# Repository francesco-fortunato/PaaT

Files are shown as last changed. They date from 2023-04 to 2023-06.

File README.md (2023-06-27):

# PaaT - Pet as a Thing!
Internet of Things project for the Internet of Things Algorithm and Services 2022/23 course held by Andrea Vitaletti and Ioannis Chatzigiannakis.

## People

[Francesco Fortunato](https://www.linkedin.com/in/francesco-fortunato-a68094181/) 

[Valerio Francione](https://www.linkedin.com/in/valerio-f-9000a557/)

[Andrea Sepielli](https://www.linkedin.com/in/andreasepielli/)

## Description

This project aims to develop a pet tracking system that utilizes an ESP32 Heltec LoRa v2 and GPS module to track pets' movements. The system allows pet owners to monitor their pets' location, view their pets' movement history, and receive alerts when their pets leave a designated area.

## Before Starting
Clone the repository
```
https://github.com/francesco-fortunato/PaaT.git
```

### Init and update the submodules
Execute `cd PaaT`.

#### Init submodule
```
git submodule init
```
#### Update the submodule
```
git submodule update
```

[Link to the user interface](https://main.d24229we7y3qnn.amplifyapp.com/)

## Final Delivery

### Docs

- [Concept](docs/Final_Concept.md)
- [Design](docs/Final_Design.md)
- [Evaluation](docs/Final_Evaluation.md)
- [Presentation](https://docs.google.com/presentation/d/1p3-u78l3DJtRwXcR-sK6B_98UEg3uL_TondBaY1GaM8/edit?usp=sharing)

### Video

- [Blog Post](https://www.hackster.io/paat/a-low-power-geofencing-application-with-riot-os-and-iot-lab-8825f0)
- [Demo](https://youtu.be/FwU-OgtWOeE)
- [Presentation](https://youtu.be/GNf6_sShy98)

## First Delivery

### Docs
- [Concept](docs/Concept.md)
- [Design](docs/Design.md)
- [Evaluation](docs/Evaluation.md)

### Video
- [Link to Youtube Video](https://youtu.be/oAYv7sOTY6s)

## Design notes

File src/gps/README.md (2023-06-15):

# Paat using Wi-Fi connection and MQTT

#### UART PIN CONFIGURATION ON ESP32 HELTEC LORA32 WIFI (V2)

In order to let the E108-GN02D GPS module work with ESP32 Heltec Lora V2 in Riot OS, we should edit the default pins of UART configuration:

Open the file `RIOT/boards/esp32-heltec-lora32-v2/include/periph_conf.h`

Edit the lines:

```
#ifndef UART1_TXD
#define UART1_TXD   GPIO10  /**< direct I/O pin for UART_DEV(1) TxD */
#endif
#ifndef UART1_RXD
#define UART1_RXD   GPIO9   /**< direct I/O pin for UART_DEV(1) RxD */
```

To make them like this:

```
#ifndef UART1_TXD
#define UART1_TXD   GPIO17  /**< direct I/O pin for UART_DEV(1) TxD */
#endif
#ifndef UART1_RXD
#define UART1_RXD   GPIO16   /**< direct I/O pin for UART_DEV(1) RxD */
```

Then connect the TXD of the GPS to PIN 16 and the RXD of the GPS to PIN 17

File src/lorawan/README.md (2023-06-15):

# PaaT based on LoRa

This folder contains the main.c file of the app using LoRa, along with the Makefile.

This code is used to make simulation on FIT IOT-LAB by using the board st-lrwan1 in the Saclay site. Compile it using `make all term`, then inside bin/b-l072z-lrwan1 you will find the lorawan.elf file. 

Let's go through the code and understand its main components:

#### Joining the LoRaWAN Network:

The application is using Over-The-Air Activation (OTAA), so it converts identifiers and keys to byte arrays.
The code sets the LoRaWAN data rate and checks if the device has already joined the network. If not, it attempts to join the network using the joinLoRaNetwork() function, a function defined since sometimes the join is not successful, which the purpose is to retry if the join fails.
If the network join is successful, the configuration is optionally saved to EEPROM.

#### Sending Geofence Request:

The code allocates memory for a geofence request message and constructs the JSON message using the "geofence" keyword.
The message is then sent using the semtech_loramac_send() function.

#### Receiving Geofence Data:

After a delay of 2 seconds, the code wakes up a receiver thread (_recv) to receive geofence data.
The received message is parsed and the geofence values are extracted and stored in the geofence array.

#### Geofence Violation Checking:

The code enters an infinite loop where it waits for a reliable position or a timeout.
In this example, latitude and longitude values are hardcoded for demonstration purposes.

The code checks if the number of satellites is greater than or equal to 4, and if so, determines if the current position is within the geofence using the isInGeofence() function. The code is simulating a scenario in which when the board is initialized, the pet is inside the geofence, while after 10 minutes it exit.

If the geofence is violated, is turned on an LED, is encrypted and sent the latitude and longitude coordinates using AES encryption, and is performed a sleep for 300 seconds.

If the geofence is not violated, it prints a message, turns off the LED, sets soundOn and lightOn flags to false, and sleeps for 300 seconds. Of course this because there is no need to know the actual position of the pet since it is inside the geofence.

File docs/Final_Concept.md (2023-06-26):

# Concept 

This document serves as the final concept report for the project. For the previous version, please refer to [this link](https://github.com/francesco-fortunato/PaaT/blob/main/docs/Concept.md).

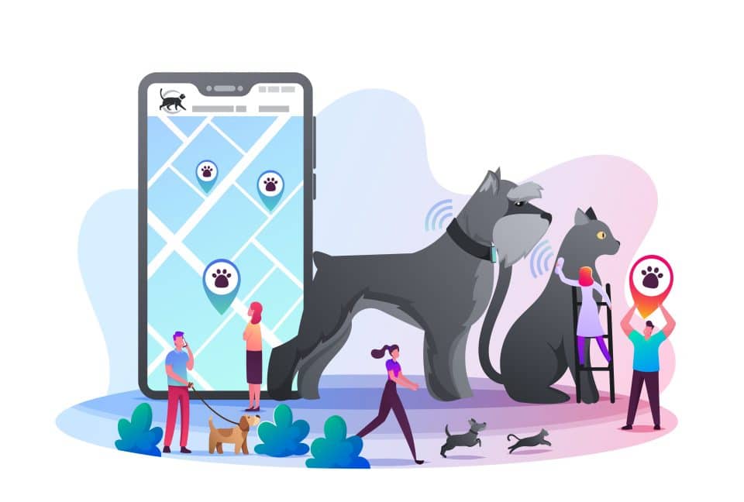
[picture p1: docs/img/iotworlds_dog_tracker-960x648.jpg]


## The Problem 

Owning a pet offers numerous health benefits, including increased exercise, outdoor activities, and social interaction. Pets provide companionship and can help alleviate feelings of loneliness and depression. However, losing a pet is an extremely distressing experience for their owners.

While the issue of lost pets is widely acknowledged, obtaining accurate statistics is challenging due to the lack of a national reporting system. In 2009, according to the American Humane Association **1 out of 3** pets become lost at some point in their lifetime (**33%**) and close to **10 million** dogs and cats are lost or stolen in the US every single year. According to the Coalition for Reuniting Pets and Families, **less than 23%** of lost pets in the United States are reunited with their owners.
We can synthesize this with:
- **over 135 millions of dogs and cats in the United State**
- **33% of ALL dogs and cats in the USA go MISSING**
- **more than 80% of missing pets are NEVER FOUND**

In 2016, [Peeva](https://peeva.co/blog/missing-pet-epidemic-facts-and-figures) conducted a survey sporadically over the course of several months in 2016 to get a more accurate gauge of the approximate percentage of owned dogs and cats in the United States that are reported lost, and of these reported lost pets (specifically dogs and cats), the percentage that are reclaimed by their owners (those that reported the pets as lost) by surveying a sample set indicative of the US pet owning population as a whole. The results and conclusions were surprising: the previous statistics reported are actually the same as their findings.
- **over 135 millions of dogs and cats in the United State**
- **33% of ALL dogs and cats in the USA go MISSING**
- **more than 80% of missing pets are NEVER FOUND**

Moreover, we conducted some studies on **HOW** pets were found. We found out that ID or Microchip, other "valid" elements, represents only the **2-10%** for helping find pets.

## A possible solution

A possible solution for the problem could be to use a GPS system. 
GPS system used for tracking pets already exists, but they presents some lacks:
- **The module cannot be disassembled**, so issues related to battery, radio or GPS malfunction cannot be fixed easily and the whole device must be replaced
- The recognized **location is not accurate** when there is **no affordable satellite signal** (and **no information** about this is given **to the end user**)
- There are **no actuators** that let the user find the pet in though scenarios, as in the night or in hidden places (bushes, walls, enclosed areas…)
- Sensors that allow user to know if his pet is steady for too long are missing (pet could have lost tracker or have health issues)
- An **history** of last day **positions** is missing
- GSM subscription is **costly** due to licencing (**€60/year**)

An **IoT GPS system**, insted, could provide:
- A **solution** for all the requirements above.
- **Improved Recovery Rates**: in case a pet gets lost, the tracking capability and low power consumption of significantly increases the chances of finding and recovering them.
- **Continuous Monitoring**: owners can access to information about their pet's movements and behavior patterns over time. 
- **Remote Access**: owners can remotely access their pet's location information through mobile applications or web interfaces.
- **Integration with Other Devices**: For example, it can be sync with smart home systems, allowing automated alerts to be sent to multiple devices or triggering actions like opening a pet door when the pet approaches. 
- **Data Analytics**: generate a wealth of data regarding a pet's activities, location history, and health metrics. This data can be analyzed to gain insights into the pet's behavior, exercise patterns, sleep quality, and more.

So, we based user requirements on the precedent ones (that were not satisfied) and on some interviews we made during the lessons.

## User Requirements

- It has to work for
  - **At least 24 hours**: in case we lose our pet it is important that the device remains active for at least one day, that could be a sufficient amount of time to track and retrieve it;
  - **At least one month**: in case we do not lose contact with our pet, it is sufficient that the device remains active for at least one month. This period of time can be used by the user if he will stay out for days, and it’s also a good trade-off between time required to retrieve the pet and efficiency consumption from a user point of view.

- Sampling time and promptly:
  - **5 min**: when we lose the contact with the pet, 5 minutes could be a sufficient amount of time to update the position, because in 5 minutes the pet could not do so much road, and the user can rescue it;

- Accuracy:
  - **10-15m**, that is a sufficient range in order to be able for the user to find his pet.
  - **False positive** and **false negative** has to be detectable.

- Security: 
  - data exchanged by the application must be **encrypted** in order to hide sensitive information (like the position of the pet) to malicious attackers, providing **confidentiality** to the end user.

- Events: 
  - {"latitude": float, "longitude": float, “sat_num”: int}: since data transfer size are in the order of 2^7 bytes (+ headers) and since we need that the system has to be energy efficient that supports a communication in the order of ≈10 km, free, **LoRa** is strongly suitable for our system.

## Offered Services

The pet tracking system will have the following features:
- **Location Tracking**: The system utilizes GPS technology to track pets' location;
- **Geofencing**: Pet owners can set up a designated area for their pets, and the system will send an alert when the pet leaves the designated area;
- **Movement history**: The system keeps track of pets' movements and displays the data in a graphical format for pet owners to review;
- **Notifications**: Pet owners receive en email when their pets leave the designated area that incities the owner to access the site.

## Service Details
To use the pet tracking system, pet owners must first attach the GPS system to their pet's collar or harness. The system is powered by a battery, and the battery life will depend on the position of the pet, if it is in the geofence the device does not track the animal, on the other hand if the pet is outside the geofence, the device will update the position every 5 minutes.

Pet owners can access the system's features through a web interface. The web interface allows pet owners to view their pets' location, movement history, and set up geofencing. 

When pet owners set up geofencing, they can define a specific area where their pet is allowed to roam. If the pet leaves the designated area, the system sends an alert to the pet owner's email address. Pet owners can then use the web interface to track their pet's location and retrieve their pet.

## Conclusion
Pet tracking is a crucial aspect of pet ownership, and this IoT Pet Tracking System can provide a reliable and efficient solution for pet owners. With location tracking, geofencing, movement history, and notifications, pet owners can keep an eye on their pets' location and ensure their pets' safety, improve recovery rates, and so on.

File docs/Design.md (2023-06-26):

# Design

## Conceptual Architecture
The pet tracking system architecture consists of two main components: an ESP32 v2 Heltec LoRa, with the GPS module. The ESP32 is responsible for collecting location data from the GPS module, processing the data, and sending it to the receivers. Then, the receivers will be responsible for sending the data to AWS cloud service for storage and analysis.

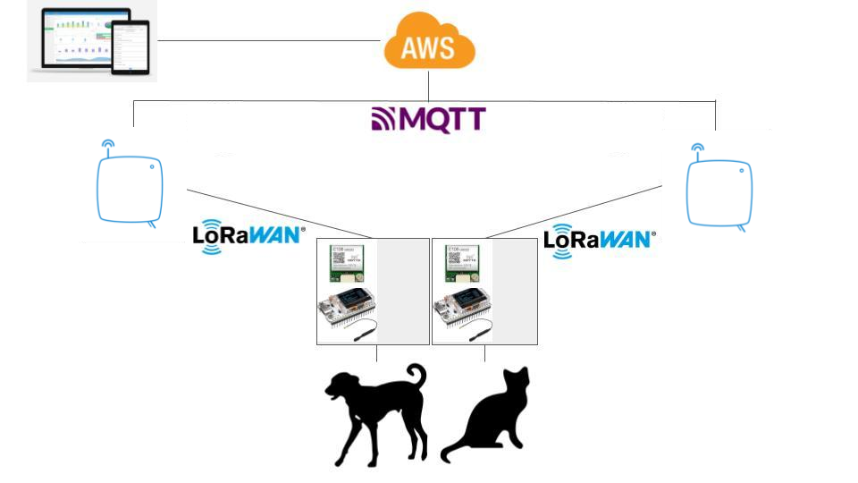
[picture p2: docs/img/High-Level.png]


The cloud service is responsible for storing the pet's location data, analyzing the data, and sending alerts to the pet owner when their pet leaves the designated area. The pet owner can access the cloud service through a web interface.

## Hardware Components
ESP32 v2 Heltec LoRa board
The ESP32 v2 Heltec LoRa board is the primary hardware component of the pet tracking system. There are two ESP32 in our system: one is responsible for collecting location data from the GPS module, processing the data, and sending it to the receiver; the other is the receiver itself, that is responsible responsible for sending the data to AWS cloud service. The two modules has a built-in LoRa transceiver that allows them to communicate with each other over long distances.

GPS Module
The GPS module is responsible for getting location data. The module communicates with the ESP32 v2 Heltec LoRa module over a serial connection.

Buzzer
The buzzer is used to emit a loud sound in the case in which the pet owner wants to find his pet and he cannot see it.

LED
The LED is also used to flash in the case in which the pet owner cannot find his pet during the night.

Battery
The battery is responsible for providing energy to the ESP32 board.

## Software Components
Core Algorithms
The pet tracking system uses several core algorithms to function correctly. The algorithms are responsible for collecting location data, processing the data, and sending alerts to the pet owner when their pet leaves the designated area.

Network Protocols
The pet tracking system uses the LoRaWAN protocol to communicate between the ESP32 v2 Heltec LoRa and GPS module and the cloud service. LoRaWAN is a low-power, wide-area network protocol that allows for long-range communication between devices.

## Network Architecture

                +-------------+
                |      DB     |
                +-------------+
                         |
                         |
                         |
             +----------------+
             | Cloud Service  |
             +----------------+
                         |
                         |
                         |
           +-----------------+
           | LoRaWAN Receiver|
           +-----------------+
                         |
                         |
                         |
          +-------------------+
          | ESP32 v2 Heltec  |
          | LoRa and GPS     |
          | Module, Battery, |
          | Buzzer, LED      |
          +-------------------+

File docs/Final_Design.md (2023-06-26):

# Design

This document serves as the final design report for the project. For the previous version, please refer to [this link](https://github.com/francesco-fortunato/PaaT/blob/main/docs/Design.md).

## Conceptual Architecture



The pet tracking system architecture consists of: 
- an Heltec ESP32 LoRa WiFi board with a GPS module, battery, buzzer and LED;
- The Things Network, that acts as a gateway for communication between the ESP32 and the cloud service. It ensures seamless data transfer and enables long-range communication.
- The cloud service, a component that stores the pet's location data, performs data analysis, and generates alerts when the pet leaves the designated area. Pet owners can access the cloud service through a user-friendly web interface.

## Hardware Components

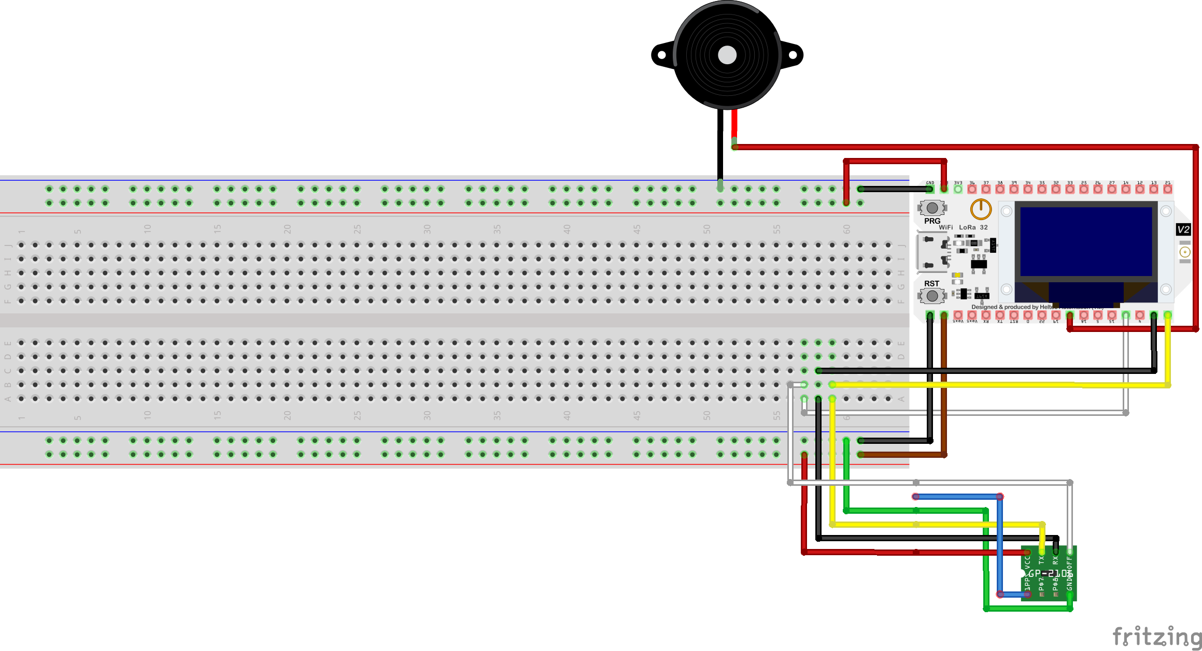
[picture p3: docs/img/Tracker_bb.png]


To enable effective pet tracking, monitoring and alerting, the pet tracking system incorporates the following hardware components:

1. ESP32 v2 Heltec LoRa board: The primary hardware component responsible for collecting location data from the GPS module, processing it, and transmitting it to the Things Network. 

2. GPS Module: The GPS module interfaces with the ESP32 v2 Heltec LoRa board through a serial connection (UART), providing accurate location data.

3. Buzzer: The system incorporates a buzzer that emits a loud sound to assist pet owners in locating their pets.

4. LED: An LED is integrated into the system to provide visibility during nighttime, aiding pet owners in locating their pets.

5. Battery: The battery serves as the primary power source for the ESP32 board, ensuring uninterrupted operation.

## Software Components

### Core Algorithm:

The algorithm works as follow:

#### Joining the LoRaWAN Network:

The application is using Over-The-Air Activation (OTAA).
The code sets the LoRaWAN data rate and checks if the device has already joined the network. If not, it attempts to join the network using the joinLoRaNetwork() function, a function defined since sometimes the join is not successful, which the purpose is to retry if the join fails.

#### Sending Geofence Request:

The code allocates memory for a geofence request message and constructs the JSON message using the "geofence" keyword.
The message is then sent using the semtech_loramac_send() function.

#### Receiving Geofence Data:

The code wakes up a receiver thread (_recv) to receive geofence data.
The received message is parsed and the geofence values are extracted and stored in the geofence array.

#### Geofence Violation Checking:

The code enters an infinite loop where it waits for a reliable position or a timeout.

The code checks if the number of satellites is greater than or equal to 4, and if so, determines if the current position is within the geofence using the isInGeofence() function. 

If the geofence is violated, is turned on an LED, is encrypted and sent the latitude and longitude coordinates using AES encryption, and is performed a sleep for 300 seconds.

If the geofence is not violated, it prints a message, turns off the LED, sets soundOn and lightOn flags to false, and sleeps for 300 seconds. Of course this because there is no need to know the actual position of the pet since it is inside the geofence.

### Network Protocols

#### LoRaWAN

LoRaWAN (Long Range Wide Area Network) is an industry-standard protocol specifically designed for low-power, wide-area networks. It enables long-range communication between devices while consuming minimal power. The utilization of LoRaWAN in the pet tracking system ensures that the location data from the ESP32 v2 Heltec LoRa board and GPS module can be transmitted efficiently to the cloud service.

LoRaWAN's unique properties make it exceptionally suitable for this project. It provides long-range coverage, allowing reliable communication between the pet tracking devices and the cloud service even over considerable distances. Moreover, LoRaWAN operates in the unlicensed spectrum, ensuring cost-effective deployment and scalability, instead of nowadays solutions. By employing LoRaWAN, the pet tracking system achieves extended battery life for the tracking devices while maintaining a robust and reliable network connection.

#### MQTT (Message Queuing Telemetry Transport)

MQTT is a lightweight messaging protocol designed for efficient communication between devices in IoT applications. It follows a publish-subscribe messaging pattern, where devices can publish data to specific topics, and other devices can subscribe to those topics to receive the published data.

In our project, MQTT is used to establish a seamless connection between the cloud service and the AWS IoT Core. The Things Network (TTN) stack, integrated with MQTT, enables data transmission from the pet tracking devices to AWS IoT Core.

The utilization of MQTT offers numerous advantages. It ensures efficient and reliable data transfer, even in constrained network environments. MQTT's lightweight nature minimizes network overhead and conserves energy consumption, aligning perfectly with the low-power requirements of the pet tracking system. Furthermore, MQTT's support for Quality of Service (QoS) levels enables the system to guarantee message delivery, ensuring the pet's location data reaches the AWS IoT Core without loss or compromise.

By combining LoRaWAN and MQTT, PaaT achieves a robust and efficient network infrastructure. LoRaWAN provides long-range connectivity, while MQTT facilitates seamless integration with AWS IoT Core, allowing pet owners to access real-time location data and receive timely alerts through the cloud service's web interface.

## Network Architecture

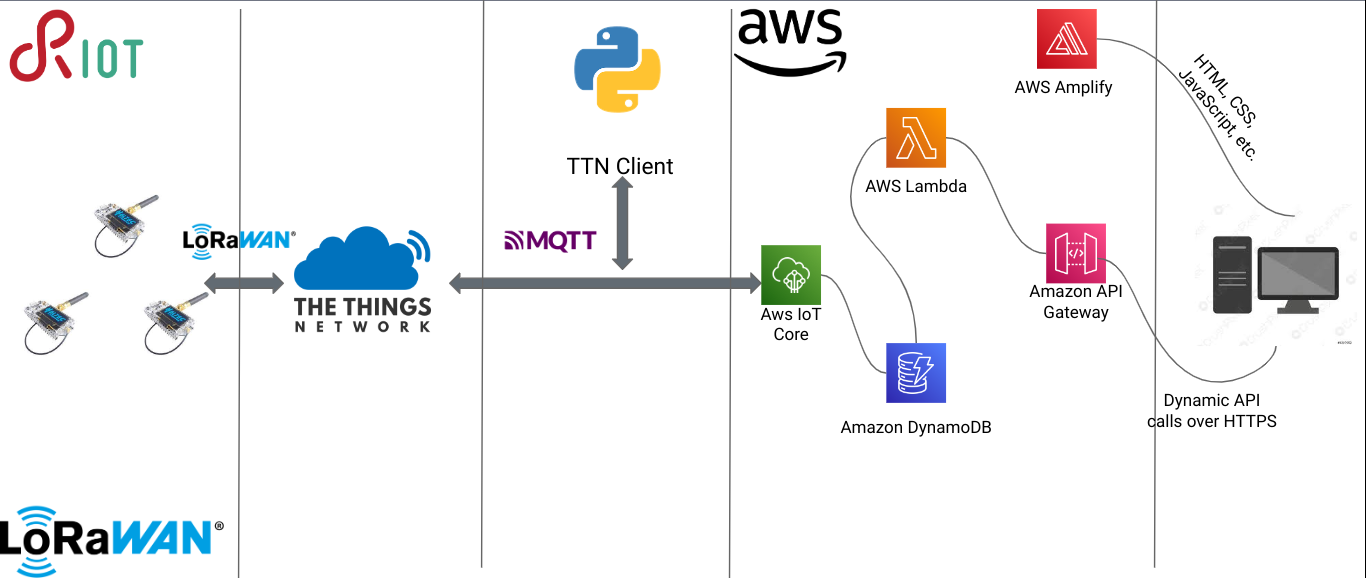
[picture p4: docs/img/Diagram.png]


The network architecture comprises the following elements:

### IoT Devices with RIOT OS
The pet tracking system utilizes IoT devices equipped with the RIOT OS (Real-Time Operating System). These devices, such as the ESP32 v2 Heltec LoRa board, incorporate the necessary hardware components, to track and monitor pets effectively. RIOT OS provides a lightweight and efficient operating system tailored for resource-constrained IoT devices, ensuring optimal performance and low power consumption.

### The Things Network (TTN)
The Things Network plays a crucial role in the pet tracking system's network architecture. TTN serves as the LoRaWAN infrastructure provider, enabling secure and reliable communication between the IoT devices and the cloud service. It facilitates the seamless transmission of location data from the IoT devices to the cloud service, ensuring efficient data flow and connectivity.

### Python client for interfacing with TTN
To facilitate the configuration of geofence boundaries, a Python TTN client is employed. This client interacts with TTN to provide the precise coordinates of the geofence to the IoT devices. By leveraging this client, the system establishes an effective means of defining and updating the designated area in which pets should remain.

### Amazon Web Services

The pet tracking system leverages several components within the AWS ecosystem to enable data storage, processing, and web interface access. The components utilized include:

- AWS IoT Core: It serves as the central hub for communication between the pet tracking devices and the cloud service. AWS IoT Core enables secure and reliable data exchange and facilitates seamless integration with other AWS services.

- DynamoDB: This NoSQL database service is employed for storing the pet's location data. DynamoDB offers scalability, high performance, and low latency access, ensuring efficient storage and retrieval of location data.

- Lambda Functions: AWS Lambda functions are utilized to perform various operations on the pet's location data, including encryption, decryption, and data processing. These serverless functions enable real-time data manipulation and facilitate seamless integration with other AWS services.

- Amplify: AWS Amplify simplifies the development process by providing a set of tools and services for building scalable and secure web applications. It enables the creation of a user-friendly web interface for pet owners to access real-time location data and receive alerts.

- API Gateway: AWS API Gateway acts as the entry point for the web interface, providing a secure and scalable API endpoint. It enables seamless communication between the web interface and the backend services, ensuring a smooth user experience.

The user interface is reachble through this [link](https://main.d24229we7y3qnn.amplifyapp.com/)

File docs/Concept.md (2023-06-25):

# Concept 

## Introduction 
Pet tracking is an essential aspect of pet ownership, and it can be challenging to keep an eye on pets at all times. This project aims to develop a pet tracking system that utilizes an ESP32 Heltec LoRa v2 and GPS module to track pets' movements. The system allows pet owners to monitor their pets' location, view their pets' movement history, and receive alerts when their pets leave a designated area.



## Features
The pet tracking system has the following features:
- location tracking: The system utilizes GPS technology to track pets' location in real-time.
- Geofencing: Pet owners can set up a designated area for their pets, and the system will send an alert when the pet leaves the designated area.
- Movement history: The system keeps track of pets' movements and displays the data in a graphical format for pet owners to review.
- Notifications: Pet owners receive en email when their pets leave the designated area that incities the owner to access the site.

## Service Details
To use the pet tracking system, pet owners must first attach the ESP32 Heltec LoRa v2 with GPS module to their pet's collar or harness. The system is powered by a battery, and the battery life will depend on the position of the pet, if it is in the geofence the device does not track the animal, on the other hand if the pet is outside the geofence, the device will update the positiono every 5 minutes.

Pet owners can access the system's features through a web interface. The web interface allows pet owners to view their pets' location, movement history, and set up geofencing. The web interface also allow to the user to active a light and a sound signal, in order to make easier find the pet in low-visibility condition.

When pet owners set up geofencing, they can define a specific area where their pet is allowed to roam. If the pet leaves the designated area, the system sends an alert to the pet owner's email address. Pet owners can then use the web interface to track their pet's location and retrieve their pet.

## Conclusion
Pet tracking is a crucial aspect of pet ownership, and this pet tracking system using ESP32 Heltec LoRa v2 and GPS module can provide a reliable and efficient solution for pet owners. With location tracking, geofencing, movement history, and notifications, pet owners can keep an eye on their pets' location and ensure their pets' safety.

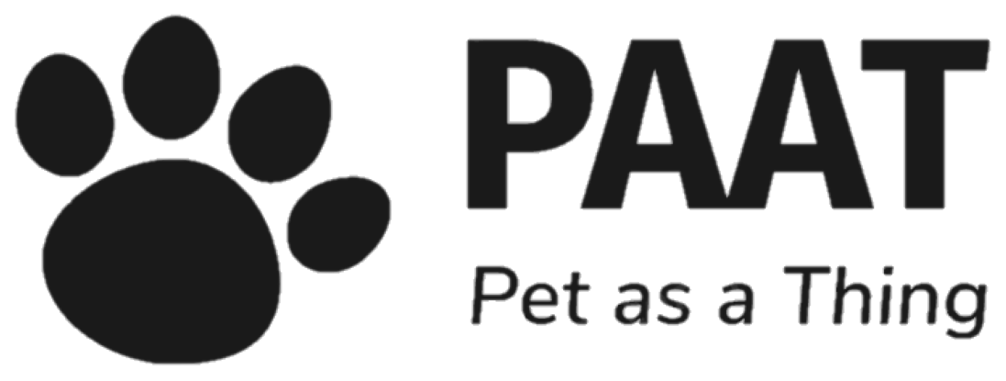
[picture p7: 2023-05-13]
cloud/user-interface/dist/paat/assets/paat.png

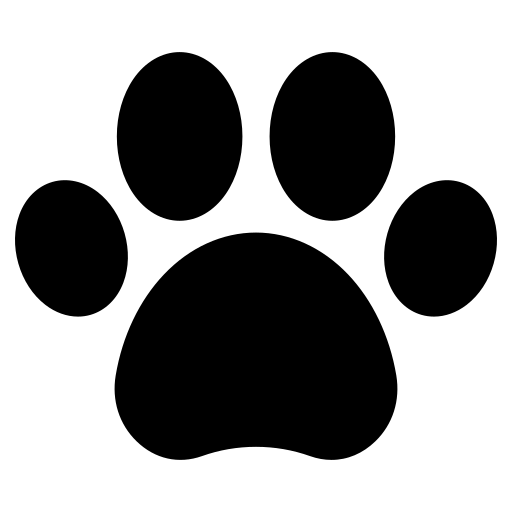
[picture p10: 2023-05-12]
cloud/user-interface/dist/paat/assets/pet.png

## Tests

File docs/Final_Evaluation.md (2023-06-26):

# Evaluation Report

This document serves as the final evaluation report for the project. For the previous version, please refer to [this link](https://github.com/francesco-fortunato/PaaT/blob/main/docs/Evaluation.md).

To evaluate the product we studied and investigated the connection via LoRa and the power consumption and management,
due to the activation of GPS only in case the animal is inside the geofence, and GPS combined with buzzer and LED in case the animal is outside the geofence instead.
The evaluation primarily focused on two key aspects: the LoRaWAN connection and power consumption and management. Detailed investigations were conducted to understand and to assess the power requirements and consumption patterns of the prototype. The following sections provide a thorough overview of the evaluation findings.

## LoRaWAN

To evaluate the LoRaWAN connection, a specialized tool offered by FIT IoT-LAB was utilized. The developed code for transmitting data was uploaded to the tool, and a series of tests were conducted. The test results demonstrated the performance of the LoRaWAN connection, with specific attention given to power consumption during data transmission.

The obtained results are graphically represented in the figure below:

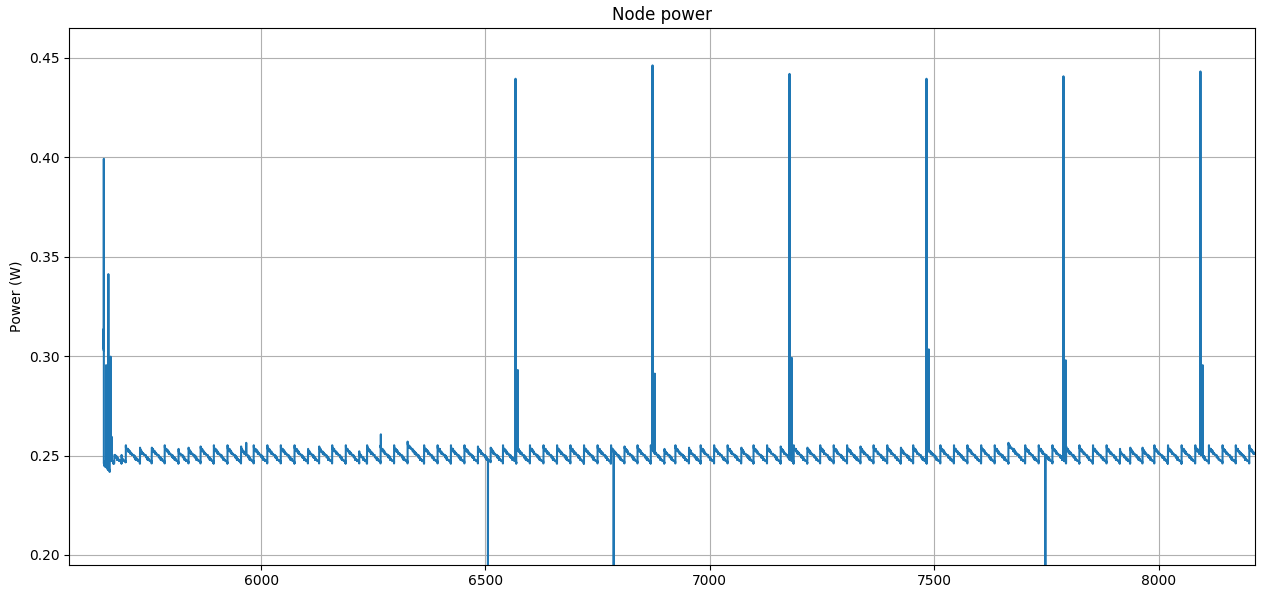
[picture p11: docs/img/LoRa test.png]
LoRa test


The graph reveals distinctive peaks in power consumption corresponding to message transmissions. Notably, the highest peak corresponds to the sending of messages, while the smallest peak aligns with the reception of response messages. To further analyze these peaks, detailed breakdowns are presented in the subsequent figures:

- Sending and response messages in detail:

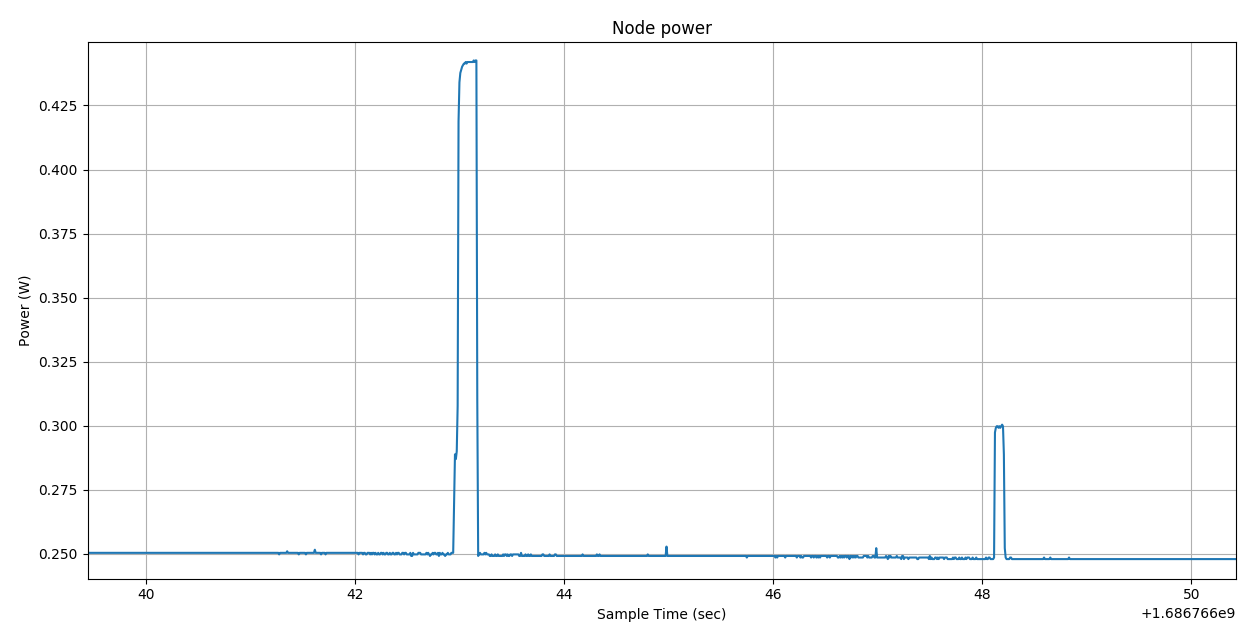
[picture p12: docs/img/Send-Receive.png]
Sending and response messages in details


- Power consumption during message transmission:
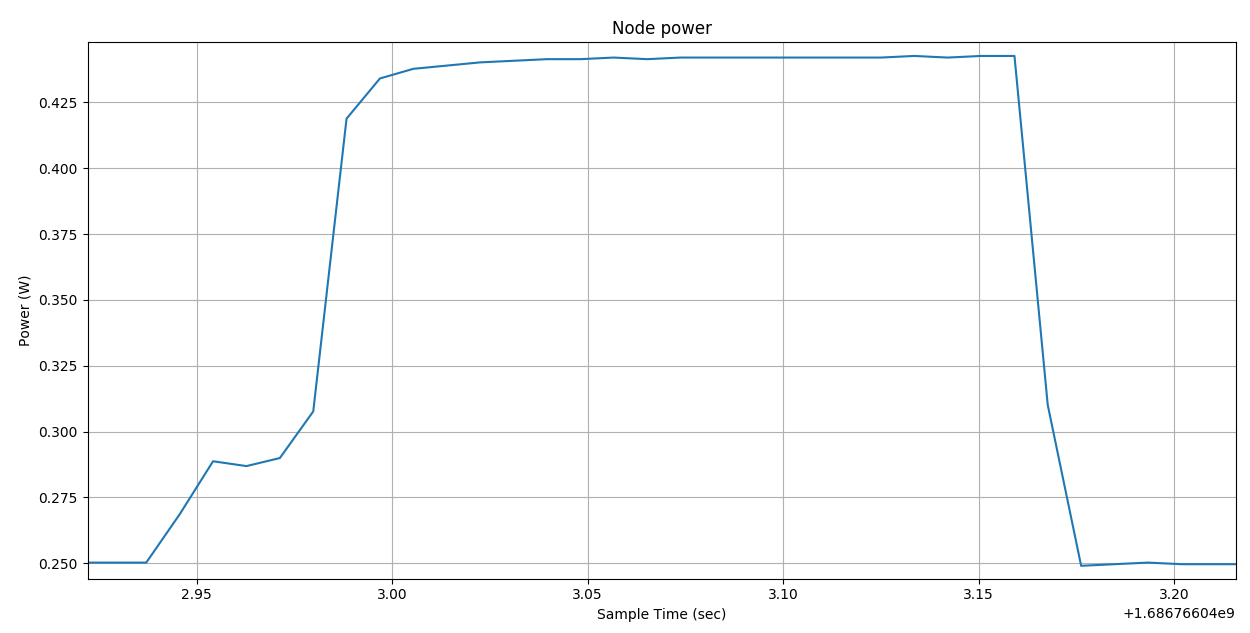
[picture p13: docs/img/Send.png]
Send message


- Power consumption during response message reception:
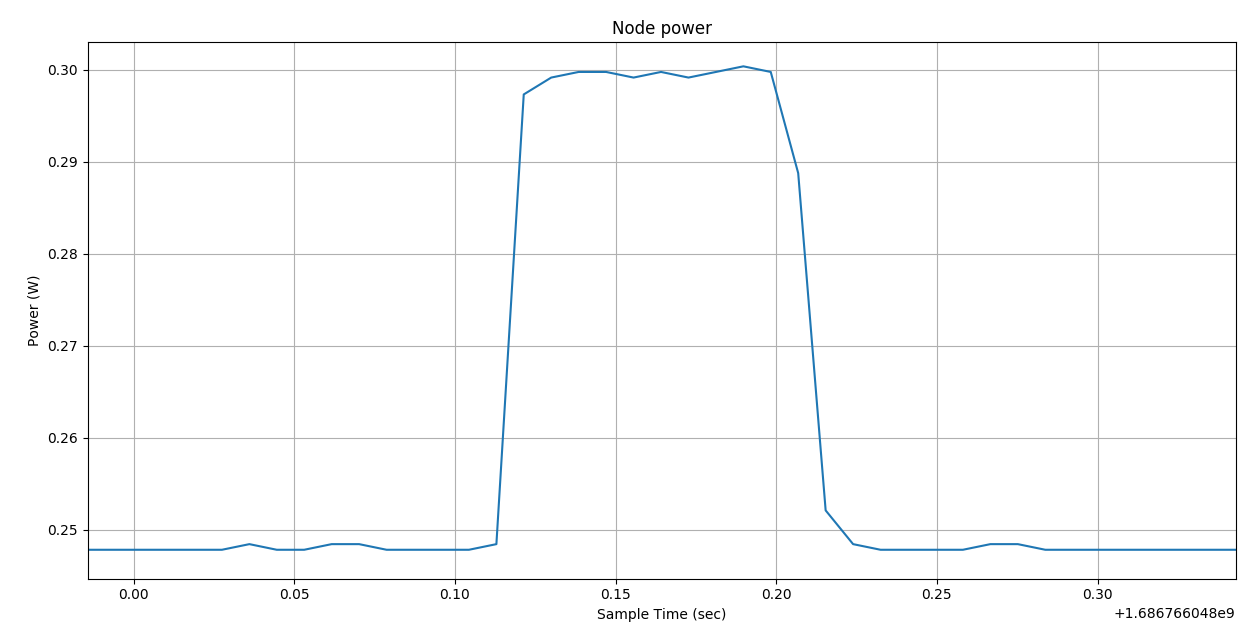
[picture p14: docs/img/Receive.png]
Response message


## Power Consumption Assessment

A comprehensive assessment of power consumption was conducted to gain a comprehensive understanding of the product's energy needs. The evaluation took into account the power requirements of the entire system. Thanks to the tool provided by FIT IoT-LAB, it was possible to accurately determine the power consumption specific to the radio component. This was achieved by calculating the area under the curve of power consumption during uplink transmission.

Uplink: (Base x Height) + (Base x Height) = (0.2 x 0.19) + (0.04 x 0.033) = 0.03932 W 

Similarly, the power consumption for receiving a response message was calculated as:

Downlink: Base x Height = 0.1 x 0.055 = 0.0055 W 

## System Autonomy Considerations

To provide a complete view of the system's power requirements, a comprehensive power consumption table has been prepared, which includes all relevant sensor components:

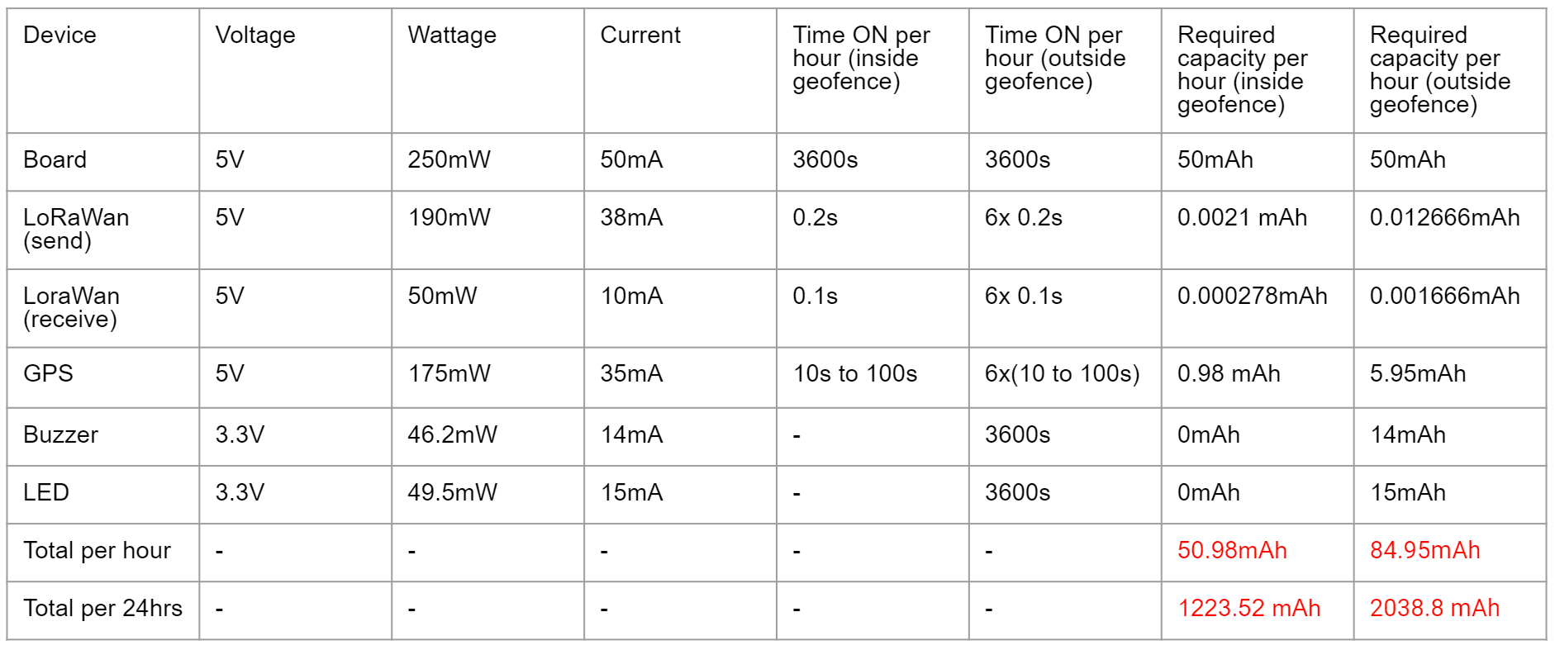
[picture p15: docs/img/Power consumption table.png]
Power Consumption Table


By analyzing the collected consumption data, it becomes possible to make accurate considerations regarding the system's autonomy. To this end, an estimation table was created, outlining the system's consumption based on various sampling times:

Estimation Table

The proposed approach suggests utilizing a sampling time of 5 minutes when the pet ventures beyond the geofence. With a 2400 mAh battery, the system is estimated to maintain a minimum autonomy of 1 day under these circumstances. Conversely, if the pet remains within the geofence, a sampling time of 1 hour is recommended. Based on the earlier power consumption figures and employing the same 2400 mAh battery, the system can operate for approximately 2 days.

## Observation

From the autonomy considerations, we see that the major consumption derives from the board, that because in Riot, at the moment, is not possible to use the deep sleep mode of the board which guarantee a greater energy savings during system downtime.

We have also studied this possibility and recalculated the values inherent in power consumption if we had the option of using this mode, and from that we have provided the new table:

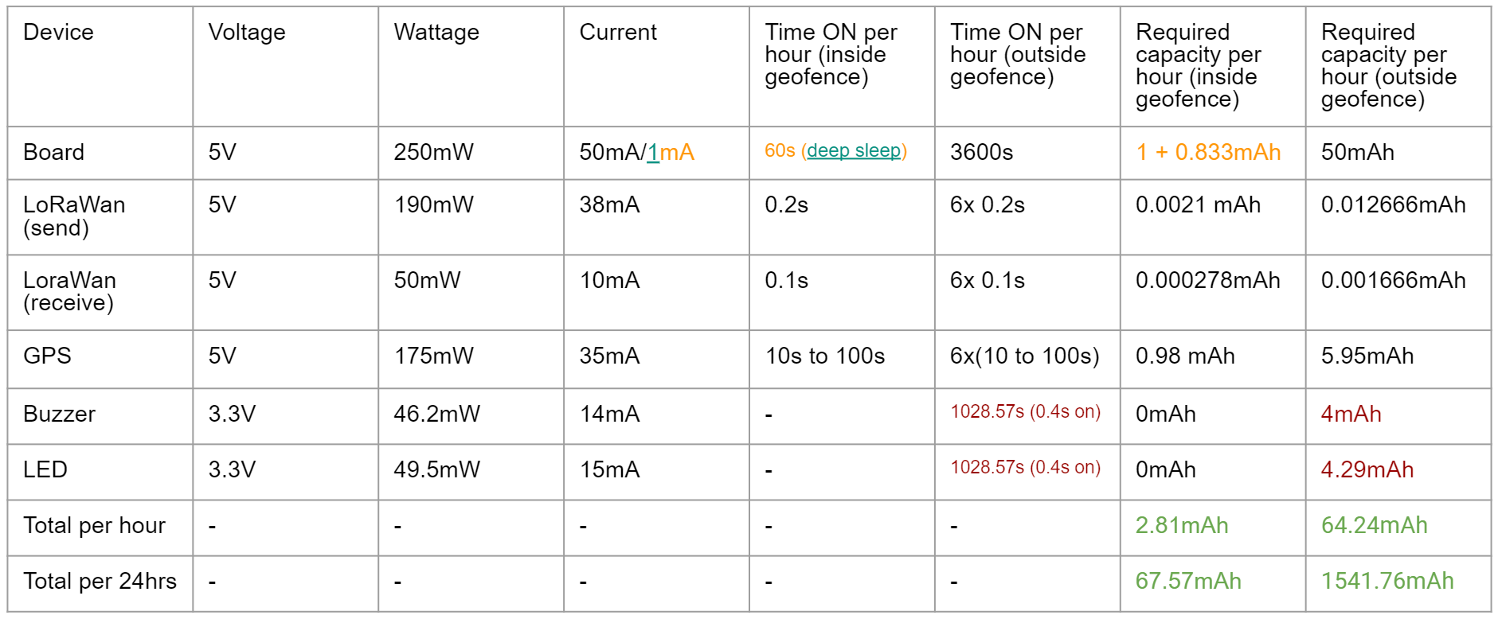
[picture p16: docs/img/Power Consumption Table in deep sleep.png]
New Power Consumption Table


Under the new hypothesis we have redefined the consumption of the system. In the first row it is possible to notice the huge battery saving when deep sleep mode is introduced whenever the pet is located inside the geofence. In the second row are shown the new values of consumption with smaller power cycles of light and sound (0.4 sec ON / 1 sec OFF): 

New Estimation Table

The new values of consumption open a new scenario in which with a battery of 2400mAh and a sampling time of 1 hour, if the device stays always inside the geofence the battery can last up to 35.5 days.
Outside geofence can be also noticed a reduction in consumption of about 500mAh.

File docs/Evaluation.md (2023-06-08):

# Evaluation

## Performance Evaluation during Development:

- Evaluation of Network Technologies:
The network technology used in the IoT pet tracking system is LoRa, which operates on the unlicensed frequency spectrum. The performance of LoRa will be evaluated based on its range, throughput, and reliability. For example, a network analyzer tool, like Wireshark, will be used to capture and analyze the network traffic, and performance metrics will be recorded, such as packet delivery ratio, latency, and jitter.

- Evaluation of Algorithms Used:
The algorithms used in the IoT pet tracking system is evaluated based on their accuracy, efficiency, and effectiveness. The accuracy of the algorithms is measured by comparing the GPS data received by the system with the actual location of the pet. The efficiency of the algorithms will be evaluated by measuring the time taken to process the data and transmit it to the cloud. The effectiveness of the algorithms is evaluated by measuring the system's ability to track the pet accurately, even in areas with poor network coverage.

- Evaluation of Embedded Devices:
The ESP32 LoRa devices used in the IoT pet tracking system is evaluated based on their power consumption and energy efficiency, given by the implemented algorithm. A power analyzer tool, such as a multimeter, will be used to measure the power consumed by the devices during operation. The data obtained will be used to calculate the energy efficiency of the devices.

- Evaluation of End-user Response Time:
The response time of the IoT pet tracking system is evaluated also from an end-user point of view. The time taken for the system to detect the location of the pet is defined in the algorithm, we had specified it in the concept file, process the data, and send it to the cloud. The response time is strictly depending on the algorithm's sampling time(specified in the concept file). 

## First Complete Version of the System:

- Evaluation of Network Technologies:
The performance of the LoRa network will be evaluated based on its reliability, scalability, and security. The network will be tested under different conditions, such as varying distances between the devices, different network loads, and network interference. The network analyzer tool, such as Wireshark, will be used to capture and analyze the network traffic, and performance metrics will be recorded, such as packet delivery ratio, latency, and jitter.

- Evaluation of Algorithms Used:
The accuracy, efficiency, and effectiveness of the algorithms used in the IoT pet tracking system will be evaluated under real-world conditions. The system will be tested in different environments, such as urban and rural areas, and the accuracy of the location data will be compared with the actual location of the pet. The efficiency of the algorithms will be evaluated by measuring the time taken to process the data and transmit it to the cloud. The effectiveness of the algorithms will be evaluated by measuring the system's ability to track the pet accurately, even in areas with poor network coverage.

- Evaluation of Embedded Devices:
The power consumption and energy efficiency of the ESP32 LoRa devices will be evaluated under real-world conditions. The devices will be tested in different environments, such as urban and rural areas, and the power consumed by the devices will be measured using a power analyzer tool, such as a multimeter. The data obtained will be used to calculate the energy efficiency of the devices.

- Evaluation of End-user Response Time:
This will involve testing the system in different environments and under varying network conditions to ensure that it functions reliably and efficiently. The user interface of the system will also be evaluated for ease of use and intuitiveness. Also user feedback can be solicited through surveys or interviews to gain insights into the system's usability and any areas for improvement.

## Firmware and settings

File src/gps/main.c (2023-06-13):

/*
 * Copyright (C) 2023 Francesco Fortunato, Valerio Francione, Andrea Sepielli
 *
 * This file is subject to the terms and conditions of the MIT License.
 * See the file LICENSE in the top level directory for more details.
 */

/**
 * @{
 *
 * @file
 * @brief       PaaT
 *
 * @authors      Francesco Fortunato <francesco.fortunato1999@gmail.com>,
 *               Valerio Francione <francione97@gmail.com>,
 *               Andrea Sepielli <andreasepielli97@gmail.com>
 *
 * @}
 */

#include <stdio.h>
#include <string.h>
#include "time.h"
#include "thread.h"

#include "periph/uart.h"
#include "periph/gpio.h"
#include "periph/i2c.h"
#include "analog_util.h"

#include "xtimer.h"
#include "minmea.h"

#include "paho_mqtt.h"
#include "MQTTClient.h"
#include "crypto/aes.h"
#include "led.h"
#define DELAY (60 * US_PER_SEC)

// MQTT client settings
#define BUF_SIZE 1024

#define MQTT_BROKER_ADDR "192.168.155.13" // After connecting to the hotspot with the pc, insert here the ifconfig wlo1
#define MQTT_TOPIC "sensor/gps"
#define MQTT_VERSION_v311 4 /* MQTT v3.1.1 version is 4 */
#define COMMAND_TIMEOUT_MS 4000

#define DEFAULT_MQTT_CLIENT_ID ""

#define DEFAULT_MQTT_USER ""

#define DEFAULT_MQTT_PWD ""

#define DEFAULT_MQTT_PORT 1883 // Default MQTT port

#define DEFAULT_KEEPALIVE_SEC 10 // Keepalive timeout in seconds

#define IS_RETAINED_MSG 0

#define PRINT_KEY_LINE_LENGTH 5

#define BUZZER_PIN GPIO23

static MQTTClient client;
static Network network;

static unsigned char buf[BUF_SIZE];
static unsigned char readbuf[BUF_SIZE];

#define GPS_UART_DEV UART_DEV(1)
#define GPS_BAUDRATE 9600
#define GPS_CE_PIN GPIO2

struct minmea_float latitudeStruct;
struct minmea_float longitudeStruct;
float latitude = 0.0;
float longitude = 0.0;
int satellitesNum = 0;
bool soundOn = false;
bool lightOn = false;
float geofenceMinLat = 0;
float geofenceMaxLat = 0;
float geofenceMinLng = 0;
float geofenceMaxLng = 0;
bool geofenceViolated;

cipher_context_t cyctx;
uint8_t key[AES_KEY_SIZE_128] = "PeShVmYq3s6v9yfB";
uint8_t cipher[AES_KEY_SIZE_128];

char nmea_buffer[MINMEA_MAX_SENTENCE_LENGTH];
struct minmea_sentence_gga frame;
int i = 0;
char c;

float geofence[8] = {0.0, 0.0, 0.0, 0.0, 0.0, 0.0, 0.0, 0.0};
char *sub_topic_geofence = "geofence";
char *emergence_topic = "actuators/";
char *topic = MQTT_TOPIC;

char stack1[THREAD_STACKSIZE_MAIN];
char stack2[THREAD_STACKSIZE_MAIN];
kernel_pid_t thread_pid_buzzer;
kernel_pid_t thread_pid_led;

static bool isInGeofence(float latitude, float longitude)
{
    // TBD: THRESHOLD ERROR
    if (latitude > geofenceMaxLat || latitude < geofenceMinLat || longitude > geofenceMaxLng || longitude < geofenceMinLng)
    {
        printf("GEOFENCE IS VIOLATED\n");
        return true;
    }
    else
    {
        return false;
    }
}

static int mqtt_disconnect(void)
{

    int res = MQTTDisconnect(&client);
    if (res < 0)
    {
        printf("mqtt_example: Unable to disconnect\n");
    }
    else
    {
        printf("mqtt_example: Disconnect successful\n");
    }

    NetworkDisconnect(&network);
    return res;
}

static int mqtt_connect(void)
{
    int ret = 0;
    MQTTPacket_connectData data = MQTTPacket_connectData_initializer;
    data.MQTTVersion = MQTT_VERSION_v311;
    data.clientID.cstring = DEFAULT_MQTT_CLIENT_ID;
    data.username.cstring = DEFAULT_MQTT_USER;
    data.password.cstring = DEFAULT_MQTT_PWD;
    data.keepAliveInterval = 60;
    data.cleansession = 1;

    printf("MQTT: Connecting to MQTT Broker from %s %d\n",
           MQTT_BROKER_ADDR, DEFAULT_MQTT_PORT);
    printf("MQTT: Trying to connect to %s, port: %d\n",
           MQTT_BROKER_ADDR, DEFAULT_MQTT_PORT);
    ret = NetworkConnect(&network, MQTT_BROKER_ADDR, DEFAULT_MQTT_PORT);
    if (ret < 0)
    {
        printf("MQTT: Unable to connect\n");
        return ret;
    }

    printf("user:%s clientId:%s password:%s\n", data.username.cstring,
           data.clientID.cstring, data.password.cstring);
    ret = MQTTConnect(&client, &data);
    if (ret < 0)
    {
        printf("MQTT: Unable to connect client %d\n", ret);
        int res = MQTTDisconnect(&client);
        if (res < 0)
        {
            printf("MQTT: Unable to disconnect\n");
        }
        else
        {
            printf("MQTT: Disconnect successful\n");
        }

        NetworkDisconnect(&network);
        return res;
    }
    else
    {
        printf("MQTT: Connection successfully\n");
    }

    printf("MQTT client connected to broker\n");
    return 0;
}

static void _on_msg_received(MessageData *data)
{
    printf("gps_mqtt: message received on topic"
           " %.*s: %.*s\n",
           (int)data->topicName->lenstring.len,
           data->topicName->lenstring.data, (int)data->message->payloadlen,
           (char *)data->message->payload);

    // Extract the received string
    char *message = (char *)data->message->payload;

    // If the topic is geofence, update geofence
    if (strcmp(data->topicName->lenstring.data, "geofence") == 0)
    {

        int count = 0;

        // Parse the string and extract the geofence
        char *token = strtok(message, "[,]");
        while (token != NULL && count < 8)
        {
            geofence[count] = atof(token);
            token = strtok(NULL, ",");
            count++;
        }

        // Geofence will have this form: {lat1, lon1, lat2, lon2, ...}

        // Assign value to maxLat and minLat
        for (int i = 0; i < 8; i += 2)
        {
            float latGF = geofence[i];
            if (i == 0)
            {
                geofenceMinLat = latGF;
                geofenceMaxLat = latGF;
            }
            else
            {
                if (latGF < geofenceMinLat)
                {
                    geofenceMinLat = latGF;
                }
                if (latGF > geofenceMaxLat)
                {
                    geofenceMaxLat = latGF;
                }
            }
        }

        // Assign value to maxLon and minLon
        for (int i = 1; i < 8; i += 2)
        {
            float lonGF = geofence[i];
            if (i == 1)
            {
                geofenceMinLng = lonGF;
                geofenceMaxLng = lonGF;
            }
            else
            {
                if (lonGF < geofenceMinLng)
                {
                    geofenceMinLng = lonGF;
                }
                if (lonGF > geofenceMaxLng)
                {
                    geofenceMaxLng = lonGF;
                }
            }
        }

        printf("\nMaxLat: %f, MinLng: %f, MinLat: %f, MaxLng: %f\n",
               geofenceMaxLat, geofenceMinLng, geofenceMinLat, geofenceMaxLng);

        // Print the extracted geofence
        for (int i = 0; i < count; i++)
        {
            printf("Value %d: %.12f\n", i + 1, geofence[i]);
        }
    }
    else if (strcmp(data->topicName->lenstring.data, "actuators/") == 0)
    {

        int count = 0;
        char *token = strtok(message, "[,]");

        // String is "['true', 'true']"

        while (token != NULL && count < 2)
        {
            if (count == 0)
            {
                lightOn = (strcmp(token, "'true'") == 0 || strcmp(token, "true") == 0) ? true : false;
                token = strtok(NULL, "', ");
                count++;
            }
            else
            {
                soundOn = (strcmp(token, "'true'") == 0 || strcmp(token, "true") == 0) ? true : false;
                count++;
            }
        }

        printf("Light: %s, Sound: %s\n", lightOn ? "true" : "false", soundOn ? "true" : "false");
    }
}

// Function to print bytes
void print_bytes(const uint8_t *key, size_t size) // to be removed
{
    for (size_t i = 0; i < size; i++)
    {
        if (i != 0 && i % PRINT_KEY_LINE_LENGTH == 0)
            printf("\n");
        printf("%02x", key[i]);
    }
    printf("\n");
}

// Function to convert bytes to hex string
void bytes_to_hex_string(const uint8_t *bytes, size_t size, char *hex_string)
{
    size_t index = 0;

    for (size_t i = 0; i < size; i++)
    {
        // Format the byte as a two-digit hexadecimal string
        sprintf(&hex_string[index], "%02x", bytes[i] & 0xff);

        // Move the index two positions forward
        index += 2;
    }
    hex_string[index] = '\0';
}

// Encrypt msg using AES-128
uint8_t *aes_128_encrypt(const char *msg)
{
    printf("Unencrypted: %s\n", msg);

    size_t msg_len = strlen(msg);
    size_t padding_len = 16 - (msg_len % 16);
    size_t padded_len = msg_len + padding_len;
    uint8_t padded_msg[padded_len];

    memcpy(padded_msg, msg, msg_len);
    memset(padded_msg + msg_len, 0, padding_len);

    aes_init(&cyctx, key, AES_KEY_SIZE_128);

    print_bytes(padded_msg, padded_len);

    uint8_t *encrypted_msg = malloc(padded_len);
    if (encrypted_msg == NULL)
    {
        printf("Failed to allocate memory\n");
        return NULL;
    }

    for (int i = 0; i < (int)padded_len; i += 16)
    {
        aes_encrypt(&cyctx, padded_msg + i, encrypted_msg + i);
    }

    printf("Encrypted:\n");
    print_bytes(encrypted_msg, padded_len);

    // Convert encrypted_msg to hex string
    char *hex_string = malloc((padded_len * 2) + 1);
    if (hex_string == NULL)
    {
        printf("Failed to allocate memory\n");
        return NULL;
    }

    bytes_to_hex_string(encrypted_msg, padded_len, hex_string);

    return (uint8_t *)hex_string;
}

static void gps_rx_cb(void *arg, uint8_t data)
{
    (void)arg;
    if (data != '\n')
    {
        nmea_buffer[i++] = data;
    }
    else
    {
        nmea_buffer[i] = '\0';

        switch (minmea_sentence_id(nmea_buffer, false))
        {
        case MINMEA_SENTENCE_GGA:
        {
            if (minmea_parse_gga(&frame, nmea_buffer))
            {
                latitudeStruct = frame.latitude;
                longitudeStruct = frame.longitude;
                satellitesNum = frame.satellites_tracked;
            }
        }
        break;
        default:
            break;
        }

        i = 0;
    }
}

// Led Thread
void *toggle_led_thread(void *arg)
{

    (void)arg;
    while (1)
    {
        if (lightOn)
        {
            LED_ON(0);
        }
        else
        {
            printf("LIGHT OFF\n");
            LED_OFF(0);
            thread_sleep();
        }
    }
    return NULL;
}

// Buzzer Thead
void *buzzer_thread(void *arg)
{
    (void)arg;
    while (1)
    {
        if (soundOn)
        {
            printf("BUZZ ON\n");
            gpio_set(BUZZER_PIN);
            xtimer_usleep(400000); // Wait for 400ms
            gpio_clear(BUZZER_PIN);
            xtimer_usleep(1000000); // Wait for 1s
        }
        else
        {
            printf("BUZZ OFF\n");
            thread_sleep();
        }
    }
    return NULL;
}

int main(void)
{
    printf("You are running RIOT on a(n) %s board.\n", RIOT_BOARD);
    printf("This board features a(n) %s MCU.\n", RIOT_MCU);

    /* let LWIP initialize */
    ztimer_sleep(ZTIMER_MSEC, 10 * MS_PER_SEC);

    // Initialize network
    NetworkInit(&network);

    ztimer_sleep(ZTIMER_MSEC, 2 * MS_PER_SEC);

    MQTTClientInit(&client, &network, COMMAND_TIMEOUT_MS, buf, BUF_SIZE,
                   readbuf,
                   BUF_SIZE);

    MQTTStartTask(&client);

    // Connect to MQTT broker
    mqtt_connect();

    int ask_for_geofence;

    char *message_geofence = "Geofence";

    MQTTMessage message;
    message.qos = QOS2;
    message.retained = IS_RETAINED_MSG;
    message.payload = message_geofence;
    message.payloadlen = strlen(message.payload);

    if (client.isconnected)
    {
        if ((ask_for_geofence = MQTTPublish(&client, topic, &message)) < 0)
        {
            printf("mqtt_example: Unable to publish (%d)\n", ask_for_geofence);
        }
        else
        {
            printf("mqtt_example: Message (%s) has been published to topic %s "
                   "with QOS %d\n",
                   (uint8_t *)message.payload, topic, (int)message.qos);

            mqtt_disconnect();
            mqtt_connect();

            printf("Geofence: Subscribing to %s\n", sub_topic_geofence);
            int ret = MQTTSubscribe(&client,
                                    sub_topic_geofence, QOS2, _on_msg_received);
            if (ret < 0)
            {
                printf("Geofence: Unable to subscribe to %s (%d)\n",
                       sub_topic_geofence, ret);
            }
            else
            {
                printf("Geofence: Now subscribed to %s, QOS %d\n",
                       sub_topic_geofence, (int)QOS2);
            }
        }
    }

    // Wait for geofence
    while (1)
    {
        if (geofence[0] != 0.0)
        {
            printf("GOT GEOFENCE\n");
            int unsub = MQTTUnsubscribe(&client, sub_topic_geofence);
            if (unsub < 0)
            {
                printf("mqtt_example: Unable to unsubscribe from topic: %s\n", sub_topic_geofence);
                mqtt_disconnect();
            }
            else
            {
                printf("mqtt_example: Unsubscribed from topic:%s\n", sub_topic_geofence);
            }
            break;
        }
        else
        {
            printf("No geofence\n");
            xtimer_sleep(5);
        }
    }

    uart_init(GPS_UART_DEV, GPS_BAUDRATE, gps_rx_cb, NULL);
    gpio_init(GPS_CE_PIN, GPIO_OUT);

    thread_pid_buzzer = thread_create(stack1, sizeof(stack1),
                                      THREAD_PRIORITY_MAIN + 1,
                                      THREAD_CREATE_SLEEPING,
                                      buzzer_thread,
                                      NULL, "buzzer_thread");
    thread_pid_led = thread_create(stack2, sizeof(stack2),
                                   THREAD_PRIORITY_MAIN + 1,
                                   THREAD_CREATE_SLEEPING,
                                   toggle_led_thread,
                                   NULL, "toggle_led_thread");

    xtimer_ticks32_t last = xtimer_now();

    while (1)
    {
        if (!client.isconnected)
        {
            mqtt_connect();
        }

        // GPS power on
        gpio_write(GPS_CE_PIN, 1);
        printf("GPS power on\n");

        // Wait for reliable position or timeout
        int checks = 0;
        while (checks < 10 && satellitesNum < 4)
        {
            //xtimer_sleep(10); // TBD
            checks++;
        }

        // GPS power off
        gpio_write(GPS_CE_PIN, 0);
        printf("GPS power off\n");

        latitude = minmea_tocoord(&latitudeStruct);
        longitude = minmea_tocoord(&longitudeStruct);

        latitude = 41.89601560;
        longitude = 12.4937401988;

        char lat[16];
        char lng[16];

        sprintf(lat, "%.12f", latitude);
        sprintf(lng, "%.12f", longitude);

        char* lati = lat;
        char* longi = lng;

        //if (satellitesNum >= 4)
        {
            geofenceViolated = isInGeofence(latitude, longitude);
        }

        if (geofenceViolated)
        {
            // encrypt msg with AES
            uint8_t *lat_encrypted = aes_128_encrypt(lati);
            uint8_t *lon_encrypted = aes_128_encrypt(longi);

            printf("lati: %s, lat_encrypted: %s\n",
                   lati, (char *)lat_encrypted);

            char json[500];
            sprintf(json, "{\"id\": \"%d\", \"Latitude\": \"%s\", \"Longitude\": \"%s\", \"Satellites\": \"%d\", \"l\": \"%s\", \"s\": \"%s\"}",
                    1, lat_encrypted, lon_encrypted, satellitesNum, lightOn ? "true" : "false", soundOn ? "true" : "false");

            uint8_t *msg_to_be_sent = (uint8_t *)json;

            // Publish gps value to MQTT broker
            MQTTMessage message;
            message.qos = QOS2;
            message.retained = IS_RETAINED_MSG;
            message.payload = msg_to_be_sent;
            message.payloadlen = strlen(message.payload);

            int rc;
            if ((rc = MQTTPublish(&client, topic, &message)) < 0)
            {
                printf("mqtt_example: Unable to publish (%d)\n", rc);
                mqtt_disconnect();
                xtimer_sleep(10);
                mqtt_connect();
            }
            else
            {
                printf("mqtt_example: Message (%s) has been published to topic %s "
                       "with QOS %d\n",
                       (uint8_t *)message.payload, topic, (int)message.qos);
            }

            free(lat_encrypted);
            free(lon_encrypted);

            mqtt_disconnect();
            mqtt_connect();

            printf("Get Light and Sound: Subscribing to %s\n", emergence_topic);
            int sub = MQTTSubscribe(&client,
                                    emergence_topic, QOS2, _on_msg_received);
            if (sub < 0)
            {
                printf("Get Light and Sound: Unable to subscribe to %s (%d)\n",
                       emergence_topic, sub);
            }
            else
            {
                printf("Get Light and Sound: Now subscribed to %s, QOS %d\n",
                       emergence_topic, (int)QOS2);
            }

            bool tmp_led = lightOn;
            bool tmp_buzz = soundOn;

            for (int f = 0; f < 10; f++)
            {
                if (lightOn && tmp_led == false)
                {
                    thread_wakeup(thread_pid_led);
                }
                if (soundOn && tmp_buzz == false)
                {
                    thread_wakeup(thread_pid_buzzer);
                }
                if (lightOn != tmp_led || soundOn != tmp_buzz)
                {
                    int unsub = MQTTUnsubscribe(&client, emergence_topic);
                    if (unsub < 0)
                    {
                        printf("mqtt_example: Unable to unsubscribe from topic: %s\n", emergence_topic);
                        mqtt_disconnect();
                    }
                    else
                    {
                        printf("mqtt_example: Unsubscribed from topic:%s\n", emergence_topic);
                    }
                    mqtt_disconnect();
                    mqtt_connect();

                    printf("Get Light and Sound: Subscribing to %s\n", emergence_topic);
                    int sub = MQTTSubscribe(&client,
                                            emergence_topic, QOS2, _on_msg_received);
                    if (sub < 0)
                    {
                        printf("Get Light and Sound: Unable to subscribe to %s (%d)\n",
                               emergence_topic, sub);
                    }
                    else
                    {
                        printf("Get Light and Sound: Now subscribed to %s, QOS %d\n",
                               emergence_topic, (int)QOS2);
                    }
                }
                tmp_led = lightOn;
                tmp_buzz = soundOn;

                printf("inside waiting for godot loop\n");
                xtimer_sleep(30);
            }

            // Wait for actuators. If no actions in 5 minutes, restart loop
            printf("i'm here\n");
        }
        else
        {
            printf("Geofence is not violated, who cares about position?\n");
            printf("i'm here 2\n");

            // Sleep for 1h
            xtimer_periodic_wakeup(&last, DELAY);
        }
    }

    return 0;
}

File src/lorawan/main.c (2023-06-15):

/*
 * Copyright (C) 2023 Francesco Fortunato, Valerio Francione, Andrea Sepielli
 *
 * This file is subject to the terms and conditions of the MIT License.
 * See the file LICENSE in the top level directory for more details.
 */

/**
 * @ingroup     examples
 * @{
 *
 * @file
 * @brief       Example demonstrating the use of LoRaWAN with RIOT
 *
 * @authors      Francesco Fortunato <francesco.fortunato1999@gmail.com>,
 *               Valerio Francione <francione97@gmail.com>,
 *               Andrea Sepielli <andreasepielli97@gmail.com>
 *
 * @}
 */


#include <stdio.h>
#include <string.h>
#include "stdlib.h"
#include <time.h>
#include "random.h"

#include "periph/uart.h"
#include "periph/gpio.h"
#include "periph/i2c.h"
#include "analog_util.h"

#include "msg.h"
#include "thread.h"
#include "fmt.h"

#include "periph/pm.h"
#if IS_USED(MODULE_PERIPH_RTC)
#include "periph/rtc.h"
#else
#include "timex.h"
#include "ztimer.h"
#endif
#include "xtimer.h"

#include "net/loramac.h"
#include "semtech_loramac.h"
#include "crypto/aes.h"

#include "led.h"

#define PRINT_KEY_LINE_LENGTH 5


/* By default, messages are sent every 300s (5min) to respect the duty cycle
   on each channel */
#ifndef SEND_PERIOD_S
#define SEND_PERIOD_S       (60U)
#endif

/* Low-power mode level */
#define PM_LOCK_LEVEL       (1)

#define MAX_JOIN_RETRIES 3

char* geofence[4];

static kernel_pid_t recv_pid;
static char _recv_stack[THREAD_STACKSIZE_DEFAULT];

extern semtech_loramac_t loramac;
#if !IS_USED(MODULE_PERIPH_RTC)
static ztimer_t timer;
#endif

#ifdef USE_OTAA
static uint8_t deveui[LORAMAC_DEVEUI_LEN];
static uint8_t appeui[LORAMAC_APPEUI_LEN];
static uint8_t appkey[LORAMAC_APPKEY_LEN];
#endif

#ifdef USE_ABP
static uint8_t devaddr[LORAMAC_DEVADDR_LEN];
static uint8_t nwkskey[LORAMAC_NWKSKEY_LEN];
static uint8_t appskey[LORAMAC_APPSKEY_LEN];
#endif

#define RECV_MSG_QUEUE                   (4U)

static msg_t _recv_queue[RECV_MSG_QUEUE];
static char _recv_stack[THREAD_STACKSIZE_DEFAULT];

// Encryption 
cipher_context_t cyctx;
uint8_t key[AES_KEY_SIZE_128] = "PeShVmYq3s6v9yfB";
uint8_t cipher[AES_KEY_SIZE_128];

uint8_t *msg_to_be_sent;
char* msg_received = NULL;

char* latitude;
char* longitude;
int satellitesNum = 0;
bool soundOn = false;
bool lightOn = false;
float geofenceMinLat = 0;
float geofenceMaxLat = 0;
float geofenceMinLng = 0;
float geofenceMaxLng = 0;
bool geofenceViolated;

static bool isInGeofence(char* latitude, char* longitude)
{
    // TBD: THRESHOLD ERROR
    //The strcmp function returns a value greater than 0 if the first string is lexicographically greater than the second string, 
    //a value less than 0 if the first string is lexicographically smaller than the second string, 
    //and 0 if both strings are equal.
    int maxlatComparison = strcmp(latitude, geofence[0]);
    int maxlngComparison = strcmp(longitude, geofence[1]);
    int minlatComparison = strcmp(latitude, geofence[2]);
    int minlngComparison = strcmp(longitude, geofence[3]);
    /*
    if (maxlatComparison > 0)
    {
        printf("lat > geofence[0] (maxlat): %d\n", maxlatComparison);
    }
    else if (maxlatComparison < 0)
    {
        printf("lat < geofence[0] (maxlat): %d\n", maxlatComparison);
    }
    else
    {
        printf("lat = geofence[0] (maxlat): %d\n", maxlatComparison);
    }

    if (maxlngComparison > 0)
    {
        printf("lng > geofence[1] (maxlng): %d\n", maxlngComparison);
    }
    else if (maxlngComparison < 0)
    {
        printf("lng < geofence[1] (maxlng): %d\n", maxlngComparison);
    }
    else
    {
        printf("lng = geofence[1] (maxlng): %d\n", maxlngComparison);
    }

    if (minlatComparison > 0)
    {
        printf("lat > geofence[2] (minlat): %d\n", minlatComparison);
    }
    else if (minlatComparison < 0)
    {
        printf("lat < geofence[2] (minlat): %d\n", minlatComparison);
    }
    else
    {
        printf("lat = geofence[2] (minlat): %d\n", minlatComparison);
    }

    if (minlngComparison > 0)
    {
        printf("lng > geofence[3] (minlng): %d\n", minlngComparison);
    }
    else if (minlngComparison < 0)
    {
        printf("lng < geofence[3] (minlng): %d\n", minlngComparison);
    }
    else
    {
        printf("lng = geofence[3] (minlng): %d\n", minlngComparison);
    }
    */
    // Compare latitude and longitude strings with geofence boundaries using strcmp
    if (maxlatComparison > 0 || maxlngComparison > 0 || minlatComparison < 0 || minlngComparison < 0)
    {
        printf("GEOFENCE IS VIOLATED\n");
        return true;
    }
    else
    {
        return false;
    }
}

// Function to convert bytes to hex string
void bytes_to_hex_string(const uint8_t *bytes, size_t size, char *hex_string)
{
    size_t index = 0;

    for (size_t i = 0; i < size; i++)
    {
        // Format the byte as a two-digit hexadecimal string
        sprintf(&hex_string[index], "%02x", bytes[i] & 0xff);

        // Move the index two positions forward
        index += 2;
    }
    hex_string[index]='\0';
}

// Encrypt msg using AES-128
uint8_t* aes_128_encrypt(const char* msg)
{
    //printf("Unencrypted: %s\n", msg);

    size_t msg_len = strlen(msg);
    size_t padding_len = 16 - (msg_len % 16);
    size_t padded_len = msg_len + padding_len;
    uint8_t padded_msg[padded_len];

    memcpy(padded_msg, msg, msg_len);
    memset(padded_msg + msg_len, 0, padding_len);

    aes_init(&cyctx, key, AES_KEY_SIZE_128);

    uint8_t* encrypted_msg = malloc(padded_len);
    if (encrypted_msg == NULL) {
        printf("Failed to allocate memory\n");
        return NULL;
    }

    for (int i = 0; i < (int)padded_len; i += 16)
    {
        aes_encrypt(&cyctx, padded_msg + i, encrypted_msg + i);
    }

    // Convert encrypted_msg to hex string
    char* hex_string = malloc((padded_len * 2) + 1);
    if (hex_string == NULL) {
        printf("Failed to allocate memory\n");
        return NULL;
    }

    bytes_to_hex_string(encrypted_msg, padded_len, hex_string);

    return (uint8_t*) hex_string;
}

static void* _recv(void* arg) {
    msg_init_queue(_recv_queue, RECV_MSG_QUEUE);
    (void)arg;
    /* blocks until a message is received */
    semtech_loramac_recv(&loramac);
    loramac.rx_data.payload[loramac.rx_data.payload_len] = '\0';
    printf("PAYLOAD IS %s\n", (char*)loramac.rx_data.payload);

    
    // Allocate memory for msg_received
    msg_received = (char*)malloc(loramac.rx_data.payload_len + 1);
    if (msg_received == NULL) {
        // Handle memory allocation error
        fprintf(stderr, "Memory allocation failed\n");
        exit(1);
    }
    
    // Copy payload into msg_received
    strncpy(msg_received, (char*)loramac.rx_data.payload, loramac.rx_data.payload_len);
    msg_received[loramac.rx_data.payload_len] = '\0';
    thread_zombify();
    return NULL;
}
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

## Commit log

2023-05-12 geofence, track positions and mock gps updates
2023-05-23 added board scheme
    [Tracker.fzz]
2023-05-23 updates to sketch
    [Tracker.fzz]
2023-05-30 update gps timer and duty cycle logic
    [Tracker.fzz]
2023-06-06 manage to listen for actuators changes
2023-06-06 added first version of duty cycle + actuators threads
2023-06-07 improve emergency thread
2023-06-07 fixx buzz thread
2023-06-08 check gps inside fence, disable sound light and api timer for poweronoff
2023-06-12 fix repo + lora
    [main.c]
2023-06-13 improve geofence algorithm + handle join failures
    [main.c]
2023-06-14 add fritzing img
    [Tracker.fzz]
